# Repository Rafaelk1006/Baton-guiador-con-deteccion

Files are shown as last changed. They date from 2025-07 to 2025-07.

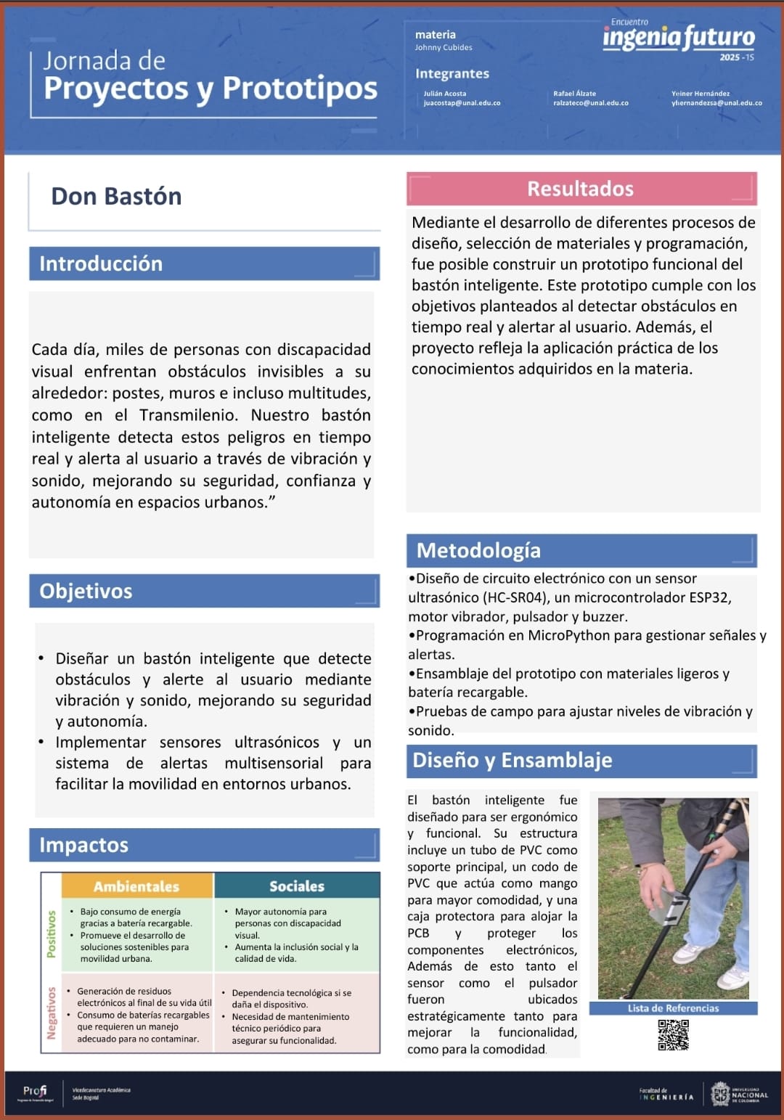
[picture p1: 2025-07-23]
Otros doumentos/Poster Don Baston.jpg

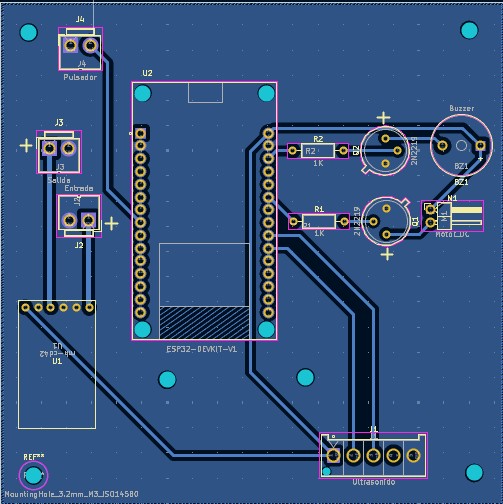
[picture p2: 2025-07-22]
PCB/Diseño Ruteo.jpg

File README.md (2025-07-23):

# Baton-guiador-con-deteccion
Repositorio para la presentación del proyecto con sus archivos

En este repositorio se presentan los archivos y el informe que conforman
el conjunto del trabajo realizado para la materia de Taller de Electrónica
por parte un grupo de estudiantes de Mecatronica para realizar el proyecto
Bastón guiador con detección "Don Bastón"

Directorio a la Wiki: https://github.com/Rafaelk1006/Baton-guiador-con-deteccion/wiki

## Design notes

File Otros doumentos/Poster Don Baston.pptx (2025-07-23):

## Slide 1

materia

Johnny Cubides

Julián Acosta
juacostap@unal.edu.co

Rafael Álzate
ralzateco@unal.edu.co

Yeiner Hernández
yhernandezsa@unal.edu.co

Don Bastón

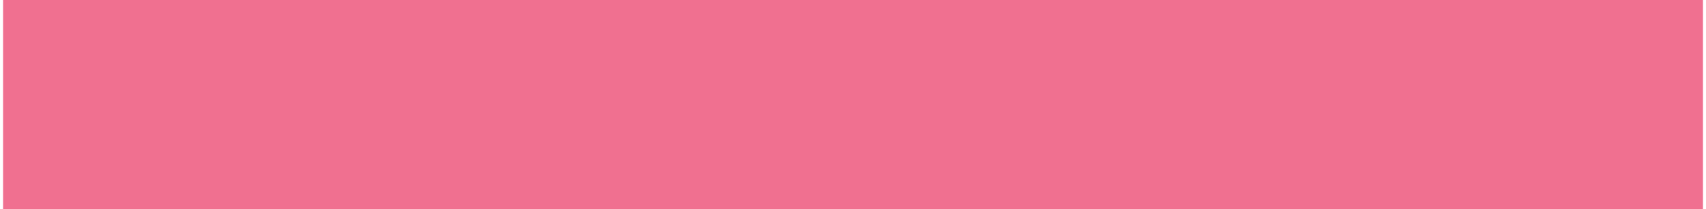
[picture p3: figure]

Resultados

Introducción

Cada día, miles de personas con discapacidad visual enfrentan obstáculos invisibles a su alrededor: postes, muros e incluso multitudes, como en el Transmilenio. Nuestro bastón inteligente detecta estos peligros en tiempo real y alerta al usuario a través de vibración y sonido, mejorando su seguridad, confianza y autonomía en espacios urbanos.”

Mediante el desarrollo de diferentes procesos de diseño, selección de materiales y programación, fue posible construir un prototipo funcional del bastón inteligente. Este prototipo cumple con los objetivos planteados al detectar obstáculos en tiempo real y alertar al usuario. Además, el proyecto refleja la aplicación práctica de los conocimientos adquiridos en la materia.

Metodología

Objetivos

- Diseñar un bastón inteligente que detecte obstáculos y alerte al usuario mediante vibración y sonido, mejorando su seguridad y autonomía.
- Implementar sensores ultrasónicos y un sistema de alertas multisensorial para facilitar la movilidad en entornos urbanos.

Impactos

- Diseño de circuito electrónico con un sensor ultrasónico (HC-SR04), un microcontrolador ESP32, motor vibrador, pulsador y buzzer.
- Programación en MicroPython para gestionar señales y alertas.
- Ensamblaje del prototipo con materiales ligeros y batería recargable.
- Pruebas de campo para ajustar niveles de vibración y sonido.

Diseño y Ensamblaje

El bastón inteligente fue diseñado para ser ergonómico y funcional. Su estructura incluye un tubo de PVC como soporte principal, un codo de PVC que actúa como mango para mayor comodidad, y una caja protectora para alojar la PCB y proteger los componentes electrónicos, Además de esto tanto el sensor como el pulsador fueron ubicados estratégicamente tanto para mejorar la funcionalidad, como para la comodidad.

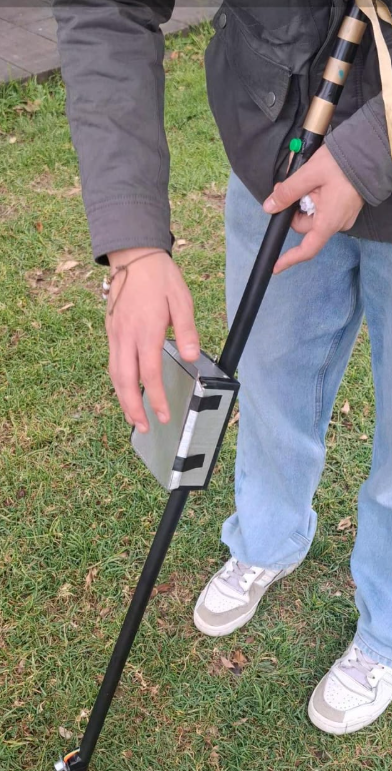
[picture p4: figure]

- Bajo consumo de energía gracias a batería recargable.
- Promueve el desarrollo de soluciones sostenibles para movilidad urbana.

- Generación de residuos electrónicos al final de su vida útil
- Consumo de baterías recargables que requieren un manejo adecuado para no contaminar.

- Mayor autonomía para personas con discapacidad visual.
- Aumenta la inclusión social y la calidad de vida.

- Dependencia tecnológica si se daña el dispositivo.
- Necesidad de mantenimiento técnico periódico para asegurar su funcionalidad.

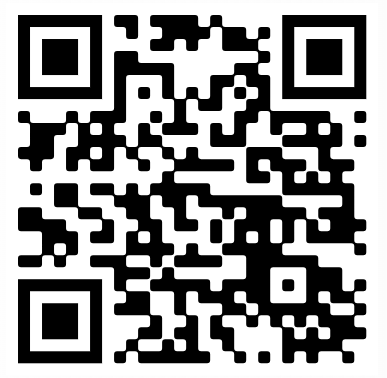
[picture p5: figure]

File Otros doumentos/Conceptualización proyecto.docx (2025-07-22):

Proyecto: Bastón de asistencia para discapacidad visual

Descripción

Una mejora a los clásicos bastones guiadores que le permitirá al usuario detectar objetos a una mayor distancia de su alcance habitual.

Situación problema

Las personas con discapacidad visual enfrentan dificultades para desplazarse con seguridad en entornos urbanos e interiores. Aunque el bastón tradicional da una forma de detección táctil esencial, este solo permite identificar obstáculos al nivel del suelo o a corta distancia, lo cual puede ser muy peligroso en ciertas situaciones (por ejemplo, al acercarse a escaleras descendentes, vehículos, o barreras a media altura).

Un ejemplo común se observa en el TransMilenio y otros sistemas de transporte público, donde personas con discapacidad visual, al avanzar con su bastón, chocan involuntariamente con otras personas, o cuando hay gran flujo de personas es difícil verlos.

En este tipo de situaciones, un bastón que emita alertas sonoras o vibración al detectar objetos podría ayudar tanto al usuario como a las personas cercanas a identificar su presencia y permitir una mejor movilidad y respeto del espacio.

Prototipo

Para mejorar la movilidad y seguridad de las personas con discapacidad visual, se desarrollará un bastón inteligente utilizando herramientas de prototipado rápido como impresión 3D, sensores de distancia y microcontroladores compatibles con MicroPython. Este bastón será diseñado como una solución de bajo costo y fácil ensamblaje, lo que permite su rápida fabricación y adaptación a distintos entornos urbanos.

El cuerpo del bastón podrá ser impreso en 3D, integrando soportes específicos para los sensores y componentes electrónicos. La detección de obstáculos se llevará a cabo mediante sensores ultrasónicos, que medirán la distancia a objetos cercanos. Cuando se detecte un obstáculo a una distancia menor al rango permitido, el sistema emitirá una alerta vibratoria y/o sonora para advertir al usuario del peligro. Además de esto, el sistema podrá indicar la distancia aproximada a la que se encuentre los objetos detectados por medio de la intensidad de la alerta

El control del sistema se gestionará a través de un microcontrolador programado en MicroPython, lo que facilitará el desarrollo del software de forma sencilla y eficiente. Esta alternativa tecnológica busca ampliar las capacidades del bastón tradicional, brindando una herramienta más segura y moderna, especialmente útil en espacios con alta afluencia de personas como estaciones de transporte o zonas urbanas concurridas y zonas más abiertas que en los que los bastones tradicionales no proveen suficiente información.

Requerimientos funcionales

1. Detección de objetos: El bastón debe ser capaz de identificar la presencia de objetos en las cercanías de donde está apuntado.
2. Alerta de presencia de objetos cercanos: Una vez detectado el objeto, el bastón debe avisar al usuario de su presencia, ya sea por señal sonora del tactil.
3. Indicar la distancia de los objetos detectados: Además de dar a conocer la presencia también debe ser capaz de identificar a grandes rasgos la distancia del objeto y el bastón y darle a conocer esa información al usuario.
4. Control de activación manual: El bastón debe permitirle al usuario controlar en qué momento el sistema de detección está activado para evitar el uso de esta de forma innecesaria.

Requerimientos no funcionales

1. Autonomía: El bastón debe funcionar de forma autónoma con una duración mínima de 5 horas de uso continuo con una sola carga.
2. Fiabilidad: El bastón debe operar de manera estable sin fallas críticas durante al menos 95% del tiempo de uso, incluso en entornos ruidosos o de alta congestión de personas o cosas.
3. Durabilidad : El bastón debe tener una vida útil mínima de 12 meses con uso frecuente, resistiendo condiciones de estrés como baches, empujones y humedad moderada sin afectar a su funcionamiento ni componentes.
4. Comodidad: El diseño ergonómico del mango y la distribución del peso deben permitir que el usuario lo use durante largos periodos sin causar cansancio en la mano o el brazo.

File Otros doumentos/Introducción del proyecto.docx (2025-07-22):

Introducción

Durante la jornada de hoy se llevó a cabo la discusión del proyecto que vamos a realizar, escogimos la opción que más gustaba a todos,se investigó la viabilidad del proyecto y sus presedentes, iniciamos las fases de diseño junto con el desarrollo de la conceptualización del proyecto, cuyo objetivo principal fue hacer la descripción del proyecto que vamos a realizar y exponer la problemática.

Durante la jornada se abordaron diferentes aspectos teóricos como sus requerimientos funcionales y no funcionales que permitieron fortalecer los conocimientos previamente adquiridos e identificar algunas complicaciones del proyecto.También se realizó una carpeta e ingresamos a draw.io para la realización del diagrama de flujo

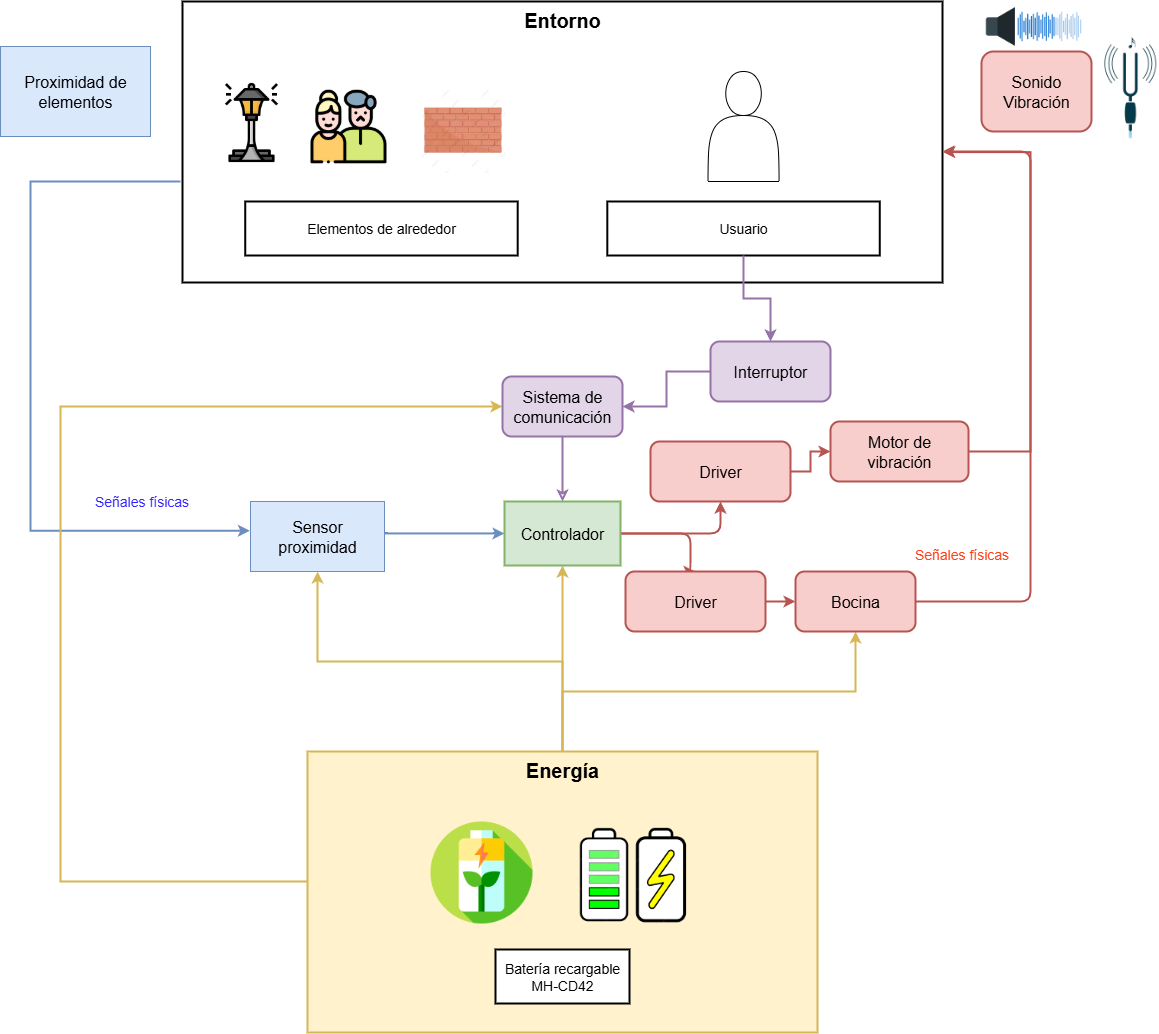
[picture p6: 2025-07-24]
Diagramas/Diagrama de cajas negras-Página-1.drawio.png

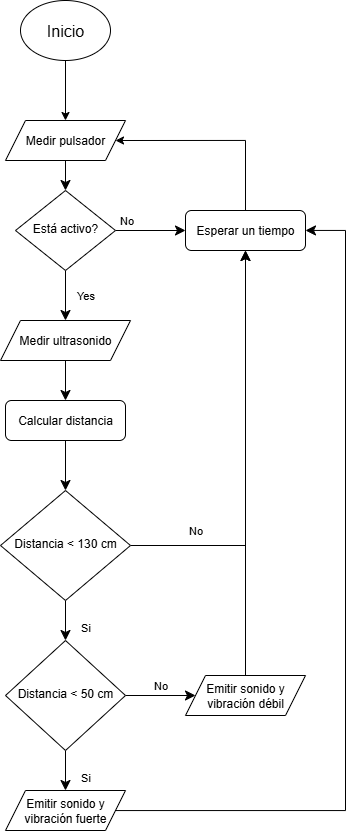
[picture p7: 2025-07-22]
Diagramas/Diagrama de tareas.drawio.png

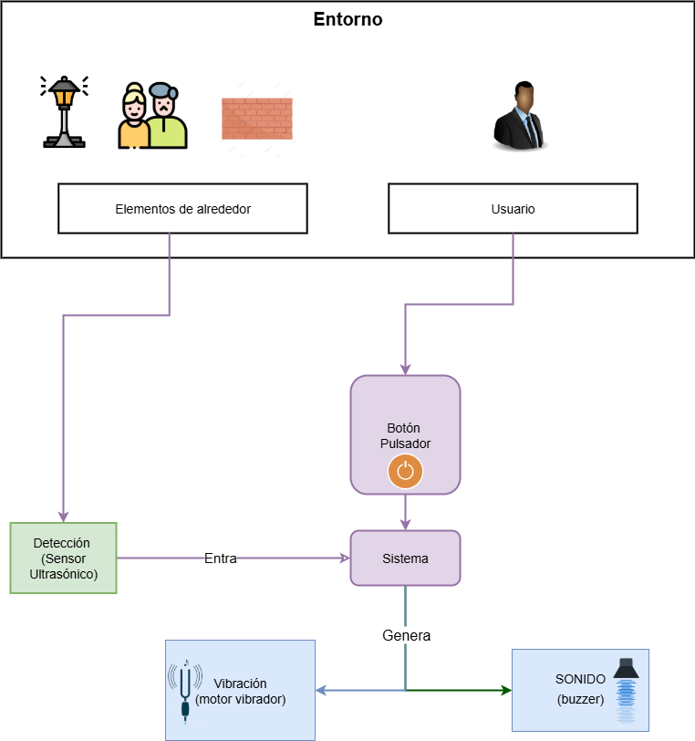
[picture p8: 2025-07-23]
Diagramas/Diagrama General.drawio.png

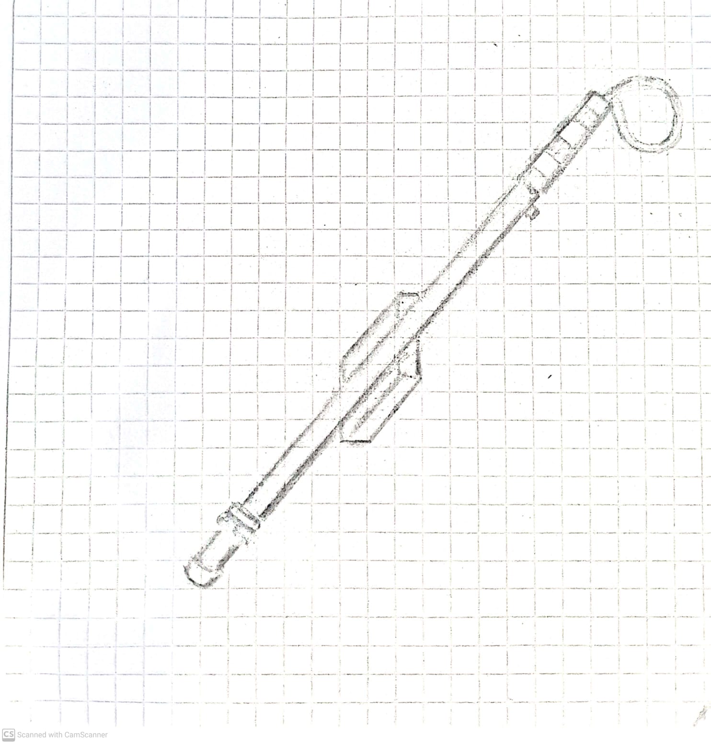
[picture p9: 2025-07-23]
Otros doumentos/Esquema sistema.jpg

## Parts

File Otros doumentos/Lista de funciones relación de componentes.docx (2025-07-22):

Funciones

- Proveer información al usuario sobre la presencia de objetos cercanos
  - Recibir datos del sensor ultrasónico
  - Procesar datos para interpretar la distancia de los objetos
  - Activa una alerta (vibración o sonido) si el obstáculo está dentro del rango de advertencia

Componentes

Entorno:

- Usuario: Persona que utiliza el sistema para obtener información de su entorno y controla el funcionamiento del mismo
- Entorno inmediato: Elementos cotidianos como (Postes, Andenes, Paredes, Personas, etc ) que pueden suponer un riesgo para el usuario y de los cuales, el sistema obtiene información

Sensores:

- Sensor de proximidad: Da información al sistema de la cercanía de objetos
- Activador: Permite al usuario controlar el funcionamiento del sistema

Actuadores:

- Generador de vibración: Avisa al usuario cuando hay un objeto cercano
- Alerta sonora: Avisa al usuario cuando hay un objeto cercano e indica cuando queda poca batería

Energía:

- Batería recargable: Proveer electricidad a los: actuadores, sensores y el controlador

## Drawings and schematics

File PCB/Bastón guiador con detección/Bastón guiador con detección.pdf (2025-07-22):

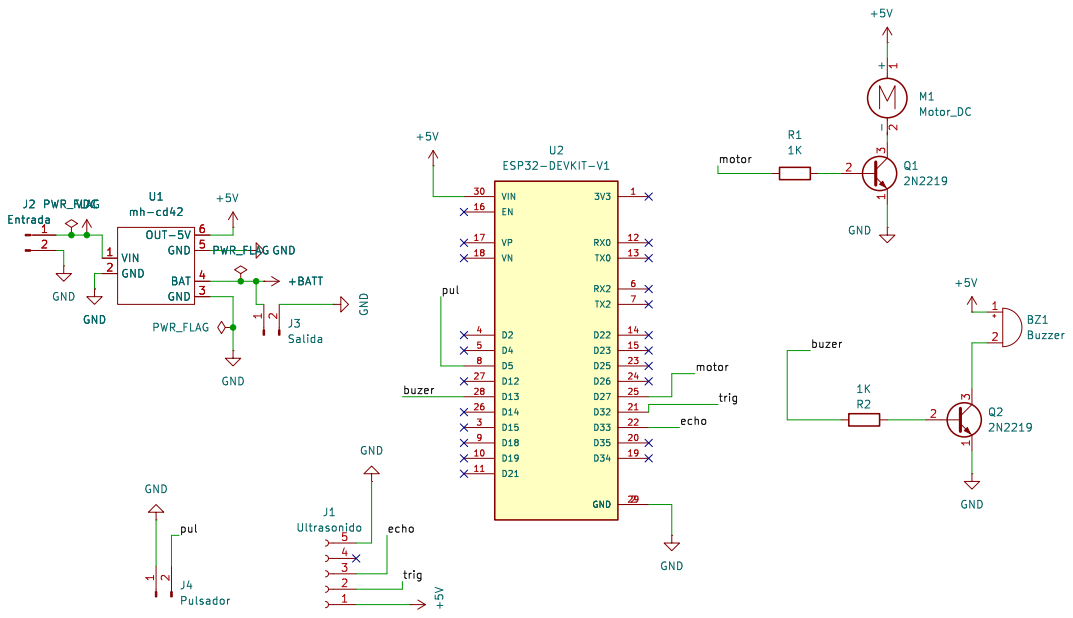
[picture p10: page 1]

File: þÿBastón guiador con þÿdetección.kicad_sch Sheet: / GND

Id: 1/1 Title: þÿBastón guiador con þÿdetección

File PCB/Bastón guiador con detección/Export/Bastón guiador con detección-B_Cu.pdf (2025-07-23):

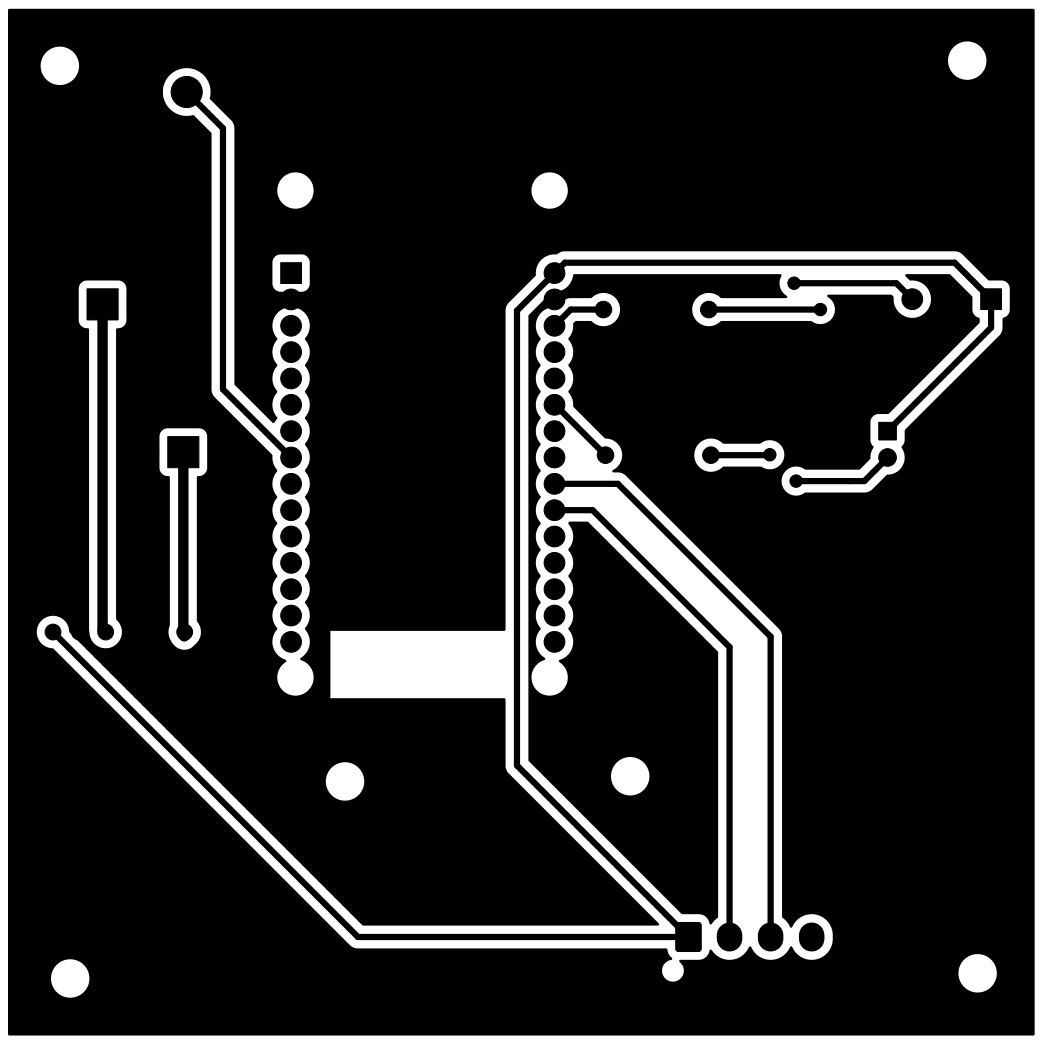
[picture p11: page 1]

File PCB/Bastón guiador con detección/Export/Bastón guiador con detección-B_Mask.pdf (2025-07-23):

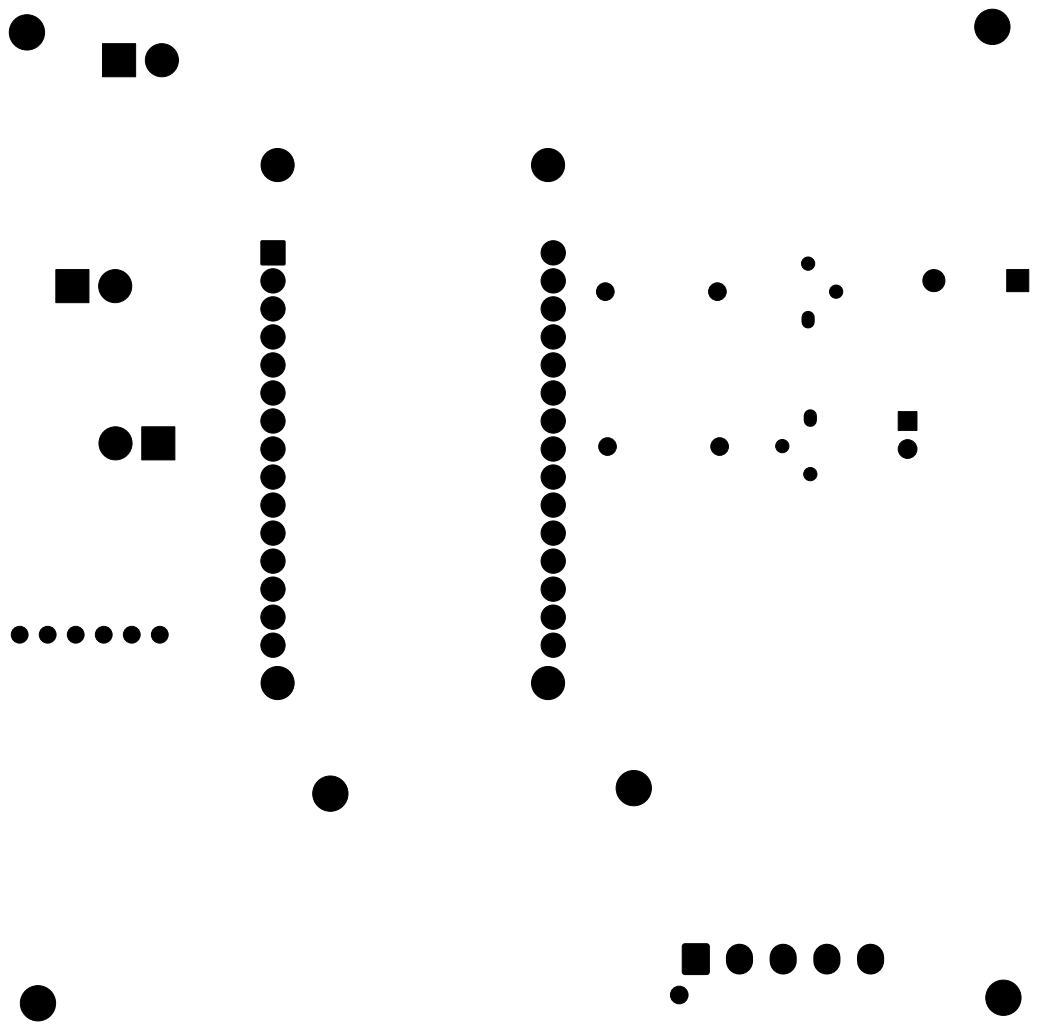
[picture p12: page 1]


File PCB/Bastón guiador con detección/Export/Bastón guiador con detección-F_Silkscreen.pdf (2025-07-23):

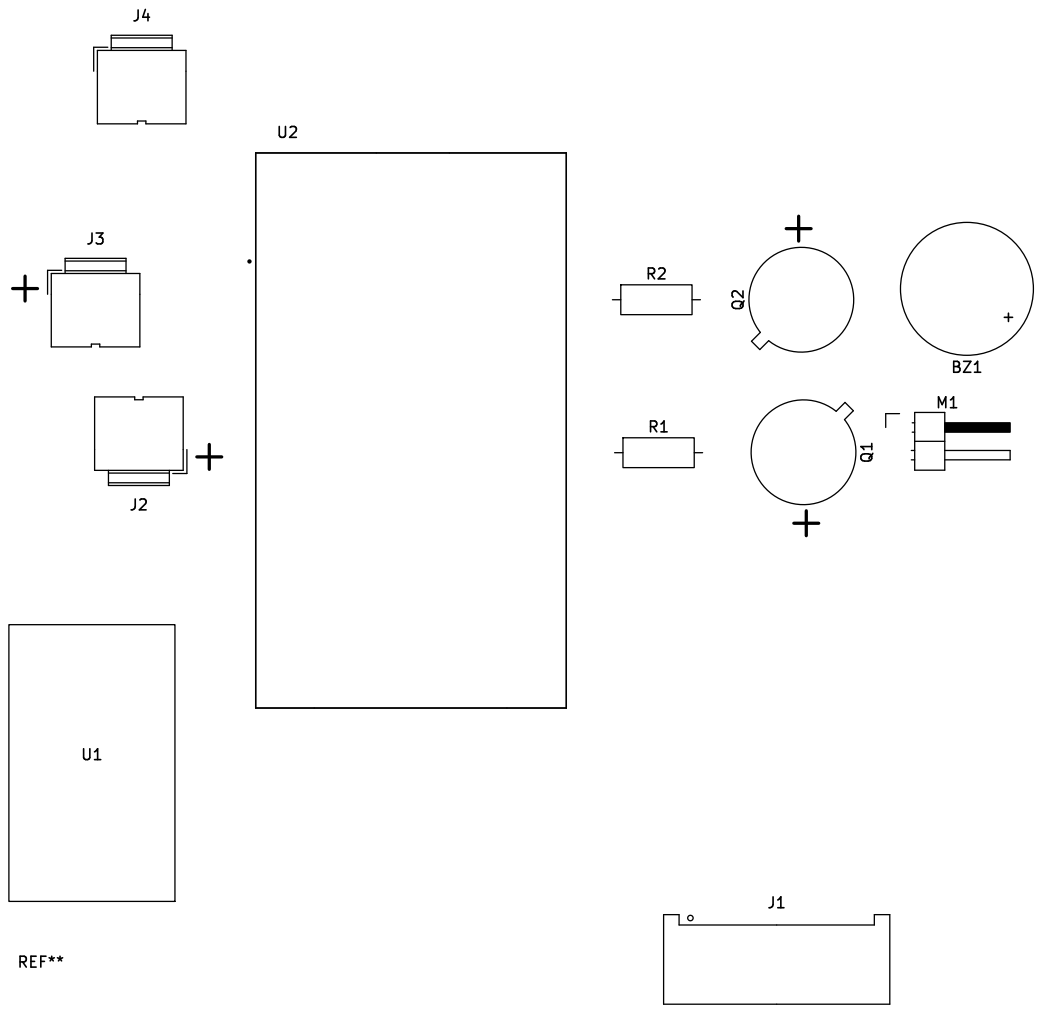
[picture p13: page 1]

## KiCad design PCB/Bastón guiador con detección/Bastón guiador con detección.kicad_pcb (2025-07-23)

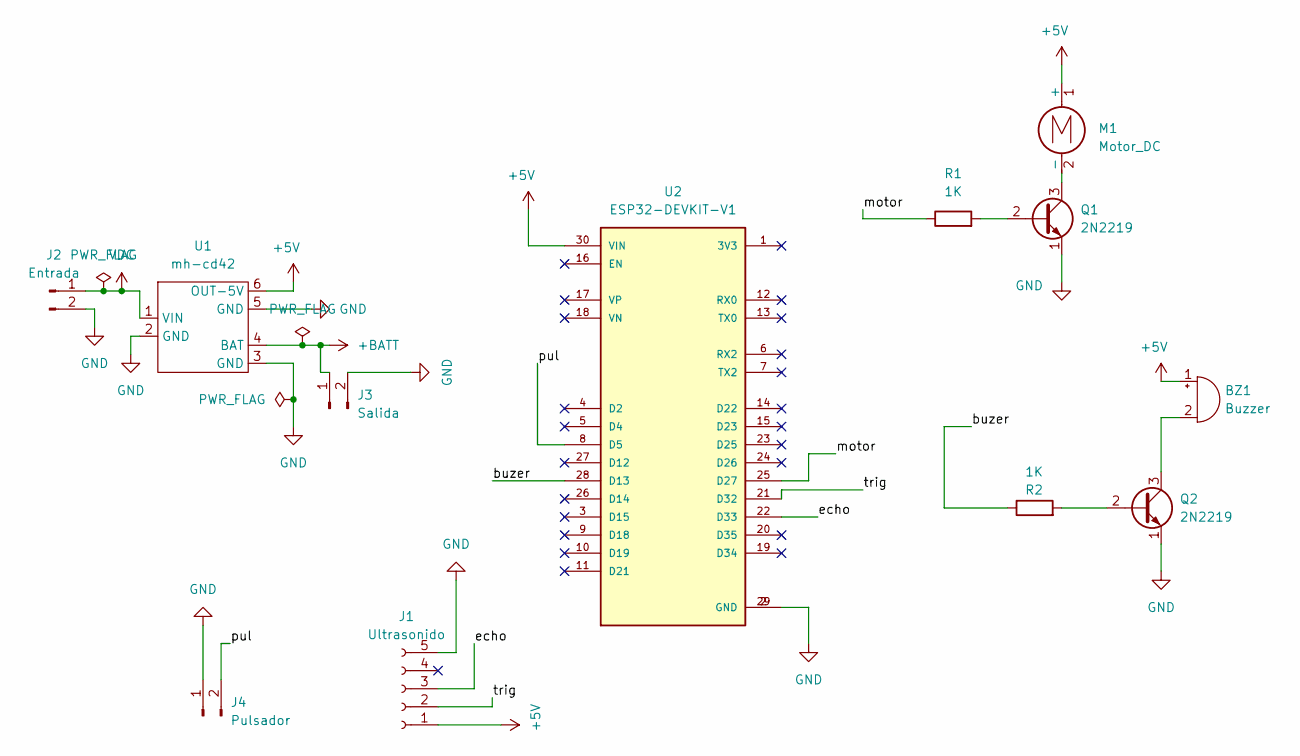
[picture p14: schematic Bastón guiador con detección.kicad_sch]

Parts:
BZ1: Buzzer; Buzzer_12x9.5RM7.6
J1: Ultrasonido; Hirose_DF63-5P-3.96DSA_1x05_P3.96mm_Vertical
J2: Entrada; JWT_A3963_1x02_P3.96mm_Vertical
J3: Salida; JWT_A3963_1x02_P3.96mm_Vertical
J4: Pulsador; JWT_A3963_1x02_P3.96mm_Vertical
M1: Motor_DC; PinHeader_1x02_P2.54mm_Horizontal
Q1, Q2: 2N2219; TO-39-3
R1, R2: 1K; R_Axial_DIN0207_L6.3mm_D2.5mm_P10.16mm_Horizontal
U1: mh-cd42
U2: ESP32-DEVKIT-V1; MODULE_ESP32_DEVKIT_V1; PARTREV N/A

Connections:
+5V: BZ1.1 (+), J1.1, M1.1 (+), U1.6 (OUT-5V), U2.30 (VIN)
+BATT: J3.1, U1.4 (BAT)
/buzer: R2.1, U2.28 (D13)
/echo: J1.3, U2.22 (D33)
/motor: R1.1, U2.25 (D27)
/pul: J4.2, U2.8 (D5)
/trig: J1.2, U2.21 (D32)
GND: J1.5, J2.2, J3.2, J4.1, Q1.1 (E), Q2.1 (E), U1.2 (GND), U1.3 (GND), U1.5 (GND), U2.2 (GND), U2.29 (GND)
unnamed: BZ1.2 (-), Q2.3 (C)
unnamed: M1.2 (-), Q1.3 (C)
unnamed: Q1.2 (B), R1.2
unnamed: Q2.2 (B), R2.2
VDC: J2.1, U1.1 (VIN)

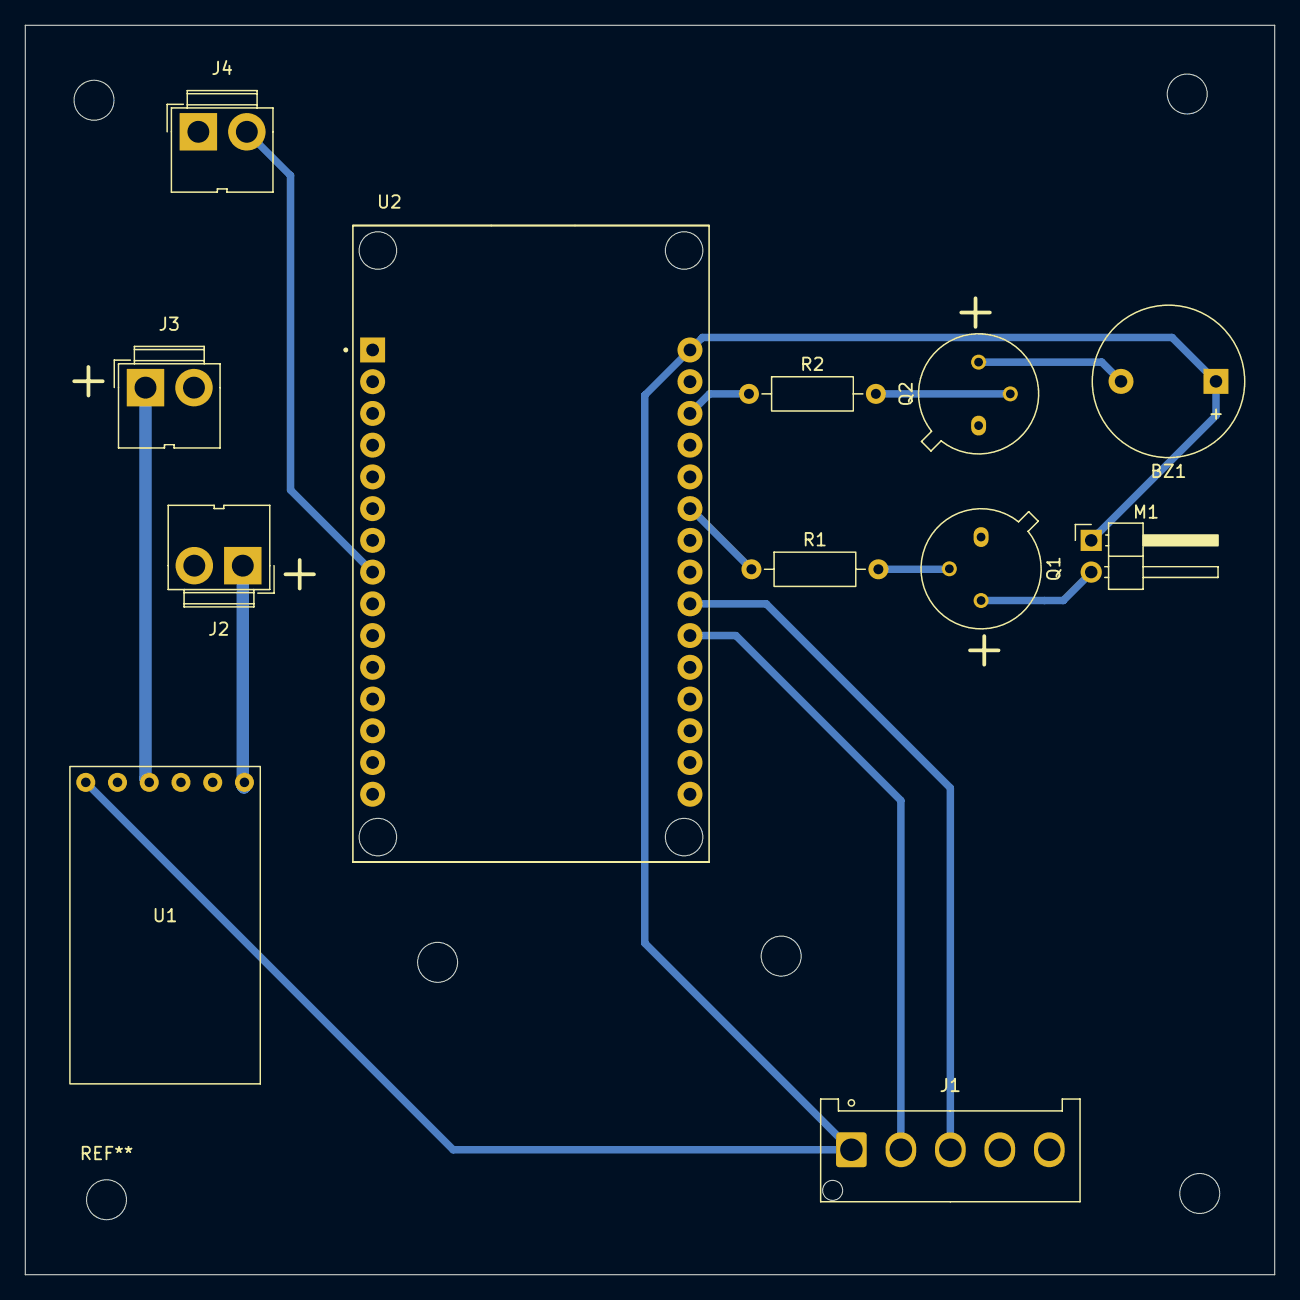
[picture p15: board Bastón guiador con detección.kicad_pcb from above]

Board: 2 copper layers, 100.0 x 100.0 mm, 12 parts (0 on the bottom side), 13 nets.

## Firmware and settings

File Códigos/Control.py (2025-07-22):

from machine import Pin, PWM, time_pulse_us
import time
from time import sleep  

# Pines
TRIG = Pin(32, Pin.OUT)
ECHO = Pin(33, Pin.IN)
BUZZER = PWM(Pin(13), freq=1000, duty=0)
MOTOR = PWM(Pin(27), freq=1000, duty=0)
BUTTON = Pin(5, Pin.IN, Pin.PULL_UP)

# Estado del sistema
sistema_encendido = False 

# Función para medir la distancia
def medir_distancia():
    """Mide la distancia en cm"""
    # Pulso de trigger
    TRIG.off()
    time.sleep_us(2)
    TRIG.on()
    time.sleep_us(10)
    TRIG.off()
    
    # Medir tiempo de respuesta
    try:
        duration = time_pulse_us(ECHO, 1, 30000)
        if duration < 0:
            return None  # Timeout
        
        # Calcular distancia (velocidad sonido = 343 m/s)
        distance = (duration * 0.034) / 2
        return distance
    except:
        return None

# Función para leer el botón con debounce
def leer_boton():
    """Lee el estado del botón y cambia el estado del sistema"""
    global sistema_encendido
    
    # Si el botón está presionado (valor 0 porque usa PULL_UP)
    if BUTTON.value() == 0:
        if not sistema_encendido:
            sistema_encendido = True
            print("=== Sistema ACTIVADO ===")
        sleep(0.05)  # Debounce simple
    else:
        if sistema_encendido:
            sistema_encendido = False
            print("=== Sistema DESACTIVADO ===")
            # Apagar salidas cuando se desactiva
            BUZZER.duty(0)
            MOTOR.duty(0)
def actualizar_salida(distancia):
    # ← AGREGADO: Validación para evitar el error
    if distancia is None:
        print("Error: Lectura de sensor inválida")
        BUZZER.duty(0)
        MOTOR.duty(0)
        return
    
    if distancia < 50:  # Cerquita
        BUZZER.duty(512)
        BUZZER.freq(2000)  # Frecuencia alta
        MOTOR.duty(800)    # Vibración fuerte
    elif distancia < 130:  # Medio- medio
        BUZZER.duty(256)
        BUZZER.freq(1000)  # Frecuencia media
        MOTOR.duty(400)    # Vibración media
    else:  # Muy lejos
        BUZZER.duty(0)
        MOTOR.duty(0)    # Vibración suave

# Bucle principal
while True:
    # Leer el estado del botón
    leer_boton()
    
    if sistema_encendido:
        distancia = medir_distancia()
        print("Distancia: ", distancia)
        actualizar_salida(distancia)
    else:
        # Asegurar que las salidas estén apagadas cuando el sistema está inactivo
        BUZZER.duty(0)
        MOTOR.duty(0)
    
    sleep(0.1)

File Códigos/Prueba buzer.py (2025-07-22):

from machine import Pin, PWM
import time

# Configurar buzzer
buzzer = PWM(Pin(4))

def tocar_tono(frecuencia, duracion):
    buzzer.freq(frecuencia)
    buzzer.duty_u16(32768)  # 50% duty cycle
    time.sleep(duracion)
    buzzer.duty_u16(0)      # Apagar

print("=== BUZZER PASIVO ===")
print("Tocando tonos de prueba...")

# Tocar 3 tonos diferentes
tonos = [500, 1000, 1500]  # Hz

for i, freq in enumerate(tonos):
    print(f"Tono {i+1}: {freq} Hz")
    tocar_tono(freq, 1)
    time.sleep(0.5)

print("Prueba completada")
buzzer.deinit()

"""
INTERPRETACIÓN DE RESULTADOS:

Buzzer:
✓ Funciona: Escuchas 3 tonos diferentes
✗ No funciona: Silencio total

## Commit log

2025-07-22 Actualización con archivos de proyecto
    Todo con lo que se trabajó
2025-07-23 Archivos fuentes
    [Bastón guiador con detección-B_Cu.gbr, Bastón guiador con detección-B_Mask.gbr, Bastón guiador con detección-B_Paste.gbr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]
